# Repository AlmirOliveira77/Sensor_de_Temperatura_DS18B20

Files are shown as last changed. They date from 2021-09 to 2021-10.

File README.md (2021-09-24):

# Sensor de Temperatura DS18B20
## Integrantes: 
 - Almir de Oliveira Pereira <br>
 - Gabriel Faustino da Silva <br>
 - Jhônata Vinícius Da Silva Negreiros

## Descrição:

<p align="justify">Simular o controle de temperatura de um reservatório de água. Por meio do uso do microcontrolador ATmega328P, manteremos a temperatura entre 18º e 22º. Ao atingir a temperatura mínima ou máxima do intervalo, um sinal sonoro será emitido pelo buzzer, o que substituiria por um sistema de liga e desliga de uma resistência para manutenção da temperatura de um aquário, por exemplo. Com a utilização de um push button, poderemos criar um "modo silencioso", no qual ao invés do buzzer ser acionado nas circunstâncias específicas, um led vermelho seria acionado. As temperaturas são exibidas em tempo real no display LCD.

A escolha dos componentes do projeto se deu pela necessidade de utilização do Sensor de Temperatura DS18B20, o que nos guiou para a utilização dos mesmos, a fim de atingir com sucesso o uso do sensor na prática desenvolvida para esta disciplina de Técnicas de Prototipagem.

No decorrer do projeto, tivemos a oportunidade conhecer mais na prática os conceitos de prototipagem e sistemas embarcados aplicados por nosso professor. E durante a execução, pudemos perceber algumas dificuldades no que diz respeito ao encontro entre os integrantes do grupo para realização do projeto em si, o que se deve ao fato de estarmos vivenciando momentos nos quais a distância também se dá pela internet e vidas pessoais. Também tivemos algumas dificuldades no desenvolvimento da placa PCB, pois utilizamos um programa recentemente conhecido pelos integrantes do grupo, mas que foi superado com o esforço contínuo e em conjunto de todos.</p>

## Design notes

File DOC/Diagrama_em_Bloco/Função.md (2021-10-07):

<ul>
<li>A Bateria fornece energia para o microcontrolador, que a recebe por meio de um regulador de tensão;</li>
<li>O Microcontrolador distribui a energia entre os componentes, bem como trata os dados recebidos pelo sensor de temperatura, e aciona outros componentes de acordo com o tratamento dos dados previamente estabelecidos em código;</li>
<li>O Sensor de Temperatura realiza a medição da temperatura no ambiente em que ele estiver e envia os dados para o microcontrolador;</li>
<li>O Módulo I2C juntamente como Display LCD recebem as informações dos dados tratados pelo Microcontrolador e os exibe para o usuário;</li>
<li>O Buzzer é acionado quando a temperatura obtida pelo Sensor e tratada pelo Microcontrolador atinge um valor específico pré-programado;</li>
<li>O Push Button desativa o Buzzer, e aciona o “modo silencioso”, juntamente aos leds.</li>
</ul>

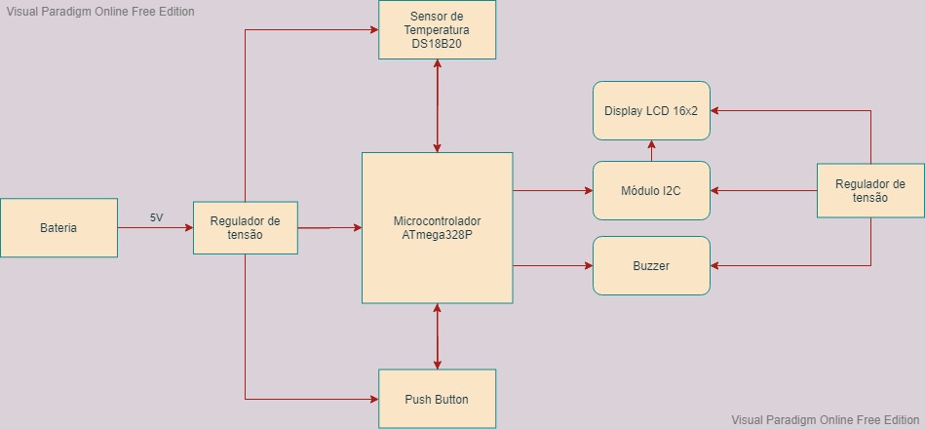
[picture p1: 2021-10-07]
DOC/Diagrama_em_Bloco/Diagrama_em_Bloco.jpeg

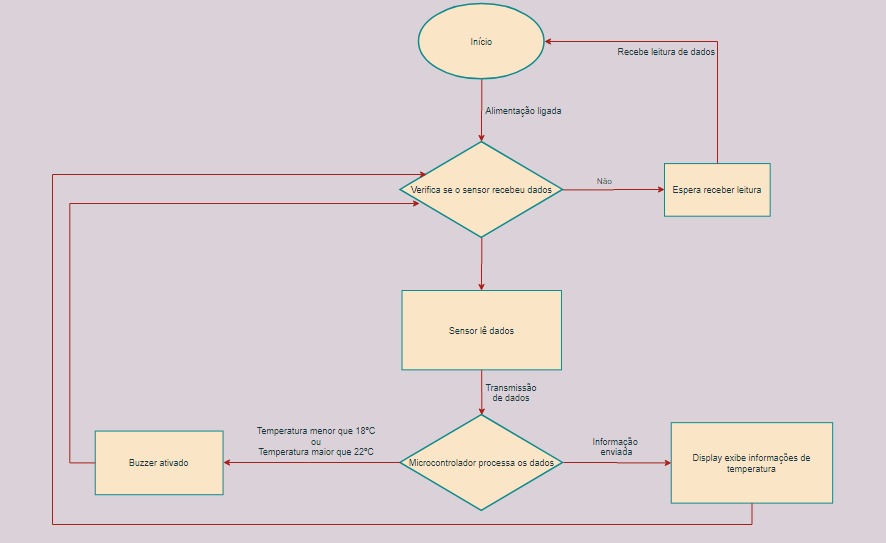
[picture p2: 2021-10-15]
FIRMWARE/Fluxograma.jpeg

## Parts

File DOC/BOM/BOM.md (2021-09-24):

<ul>
  <li>Buzzer</li>
  <li>Conector Jack</li>
  <li>Display LCD 16x2</li>
  <li>Jumpers</li>
  <li>Leds 5 mm</li>
  <li>Microcontrolador ATmega328P</li>
  <li>Módulo I2C para display LCD</li>
  <li>Push button</li>
  <li>Resistores</li>
  <li>Sensor de Temperatura DS18B20</li>
</ul>

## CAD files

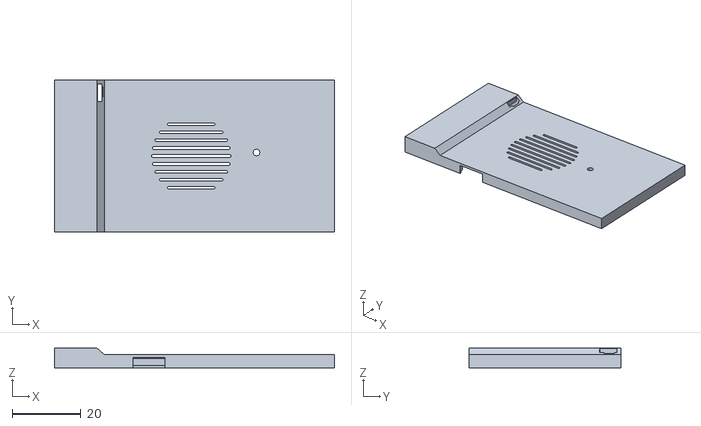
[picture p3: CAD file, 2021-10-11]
CASE/STL/Tampa.stl
81.3 x 44.1 x 5.77

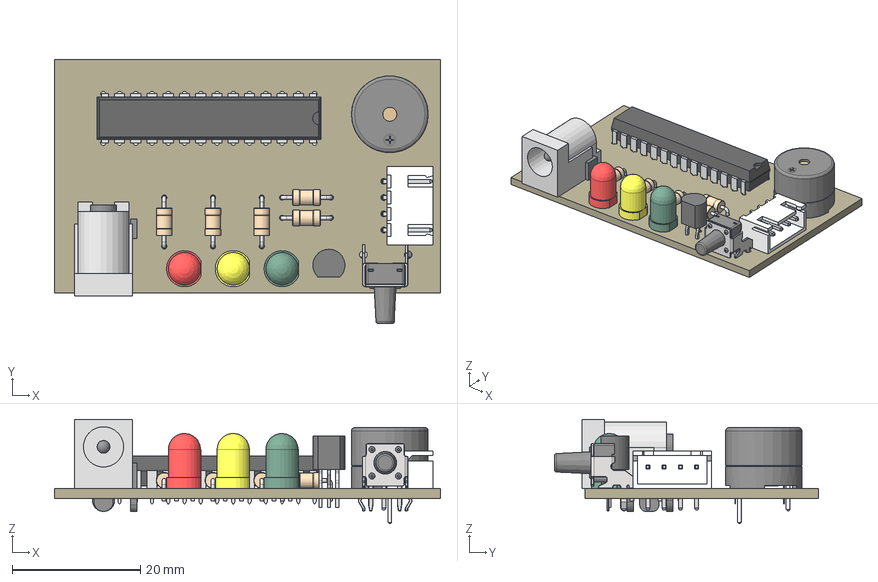
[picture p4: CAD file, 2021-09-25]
HARDWARE/Projeto_Temperatura.stp
60.3 x 41.3 x 16.3 mm
Board
TO-92
DIP28
TACTILE_SWITCH_PTH_RIGHT_ANGLE_KIT
LED5MM
LED5MM (1)
LED5MM (2)
F/CM12P
DCJ0202
0204/7
0204/7 (1)
0204/7 (2)
0204/7 (3)
0204/7 (4)
04PA

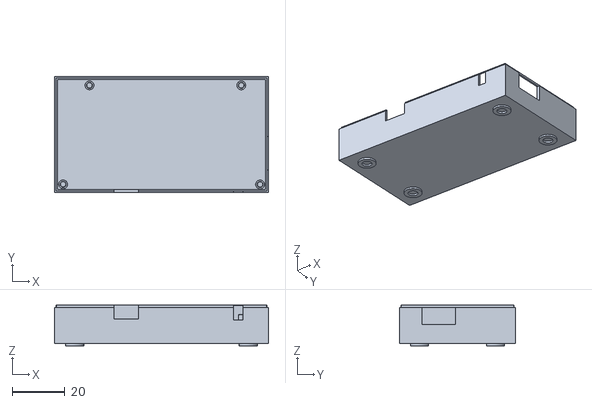
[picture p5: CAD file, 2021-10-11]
CASE/STL/Base.stl
81.3 x 44.1 x 15.4

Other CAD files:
CASE/F3D/Base.f3d
CASE/F3D/Case Completo.f3z
CASE/F3D/Tampa.f3d
HARDWARE/Projeto_Temperatura.f3d

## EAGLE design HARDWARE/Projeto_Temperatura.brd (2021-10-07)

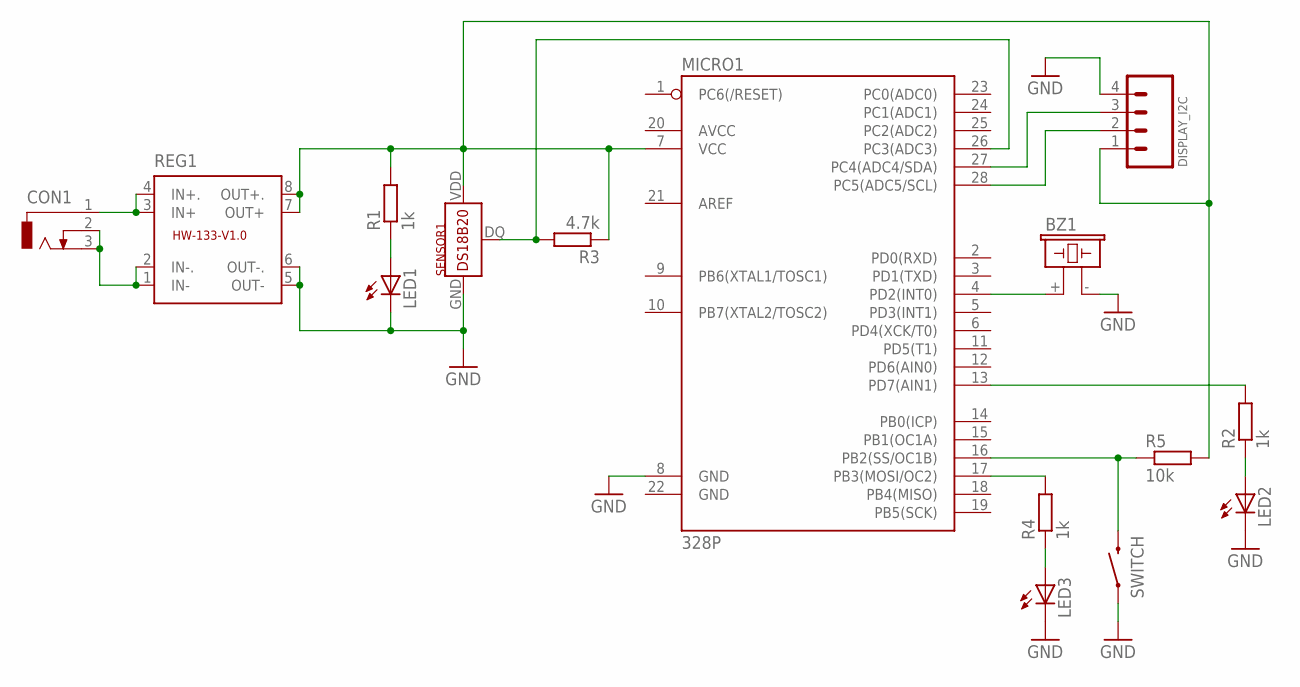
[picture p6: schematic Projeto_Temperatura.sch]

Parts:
BZ1: F/CM12P
CON1: DCJ0202
DISPLAY_I2C: MA04; 04PA
LED1, LED2, LED3: LED5MM
MICRO1: 328P; DIP28
R1, R2, R4: 1k; 0204/7
R3: 4.7k; 0204/7
R5: 10k; 0204/7
REG1: REGULADOR
SENSOR1: DS18B20; TO-92
SWITCH: MOMENTARY-SWITCH-SPST-PTH-RIGHT-ANGLE-KIT; TACTILE_SWITCH_PTH_RIGHT_ANGLE_KIT

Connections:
GND: BZ1.- (2), DISPLAY_I2C.4, LED1.K (C), LED2.K (C), LED3.K (C), MICRO1.8 (GND), REG1.5 (OUT-), REG1.6 (OUT-.), SENSOR1.GND (1), SWITCH.1
unnamed: LED2.A, R2.1
unnamed: MICRO1.13 (PD7(AIN1)), R2.2
unnamed: LED1.A, R1.1
unnamed: LED3.A, R4.1
unnamed: MICRO1.26 (PC3(ADC3)), R3.2, SENSOR1.DQ (2)
unnamed: MICRO1.17 (PB3(MOSI/OC2)), R4.2
unnamed: BZ1.+ (1), MICRO1.4 (PD2(INT0))
unnamed: MICRO1.16 (PB2(SS/OC1B)), R5.1, SWITCH.2
unnamed: DISPLAY_I2C.3, MICRO1.27 (PC4(ADC4/SDA))
unnamed: DISPLAY_I2C.2, MICRO1.28 (PC5(ADC5/SCL))
unnamed: DISPLAY_I2C.1, MICRO1.7 (VCC), R1.2, R3.1, R5.2, REG1.7 (OUT+), REG1.8 (OUT+.), SENSOR1.VDD (3)
unnamed: CON1.1, REG1.3 (IN+), REG1.4 (IN+.)
unnamed: CON1.2, CON1.3, REG1.1 (IN-), REG1.2 (IN-.)

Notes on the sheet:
REG1

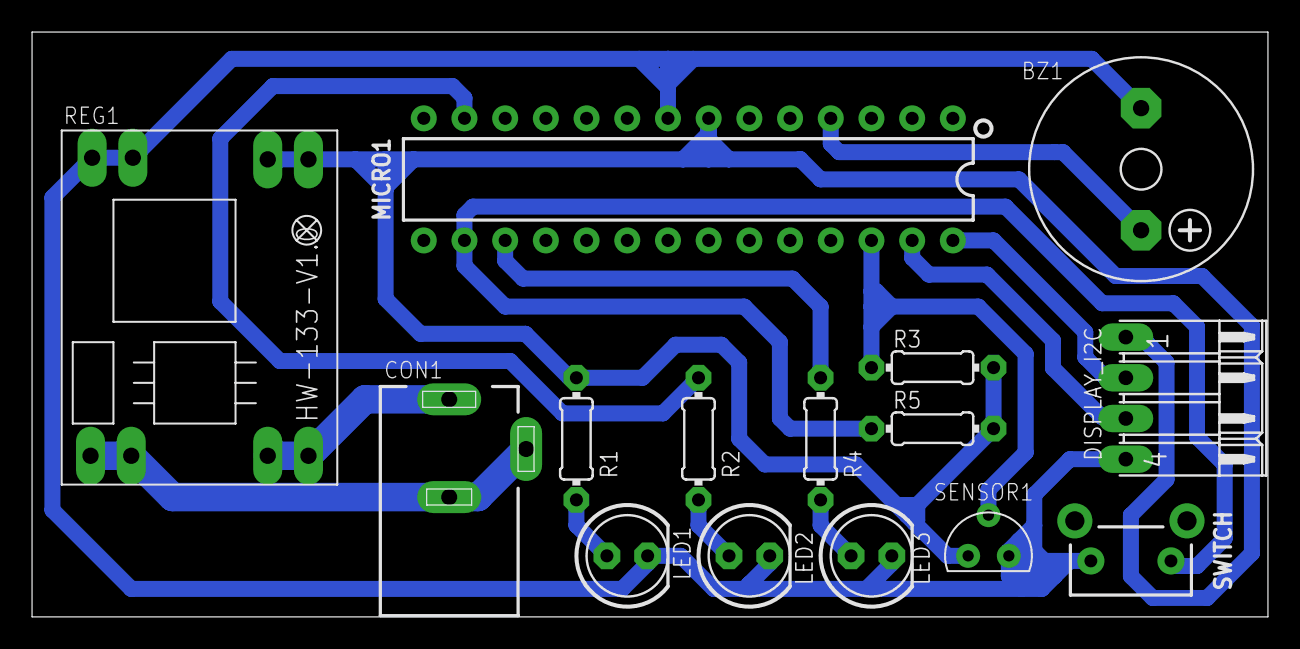
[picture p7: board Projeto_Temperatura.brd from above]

Board: 2 copper layers, 77.1 x 36.5 mm, 15 parts (0 on the bottom side), 14 nets.

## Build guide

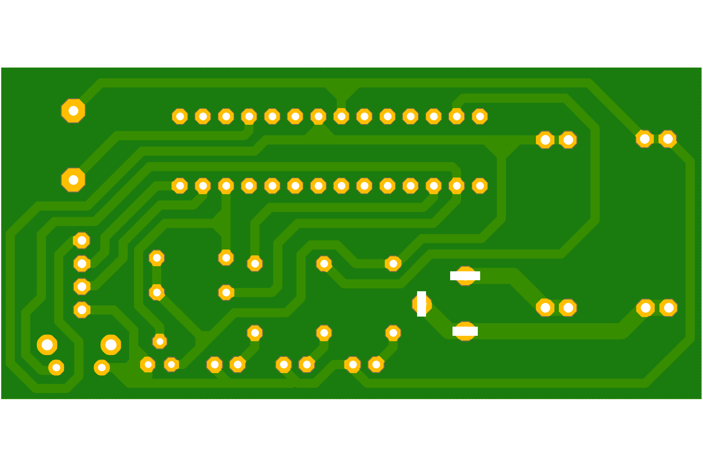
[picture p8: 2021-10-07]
HARDWARE/Prints/BOTTOM SIDE.png

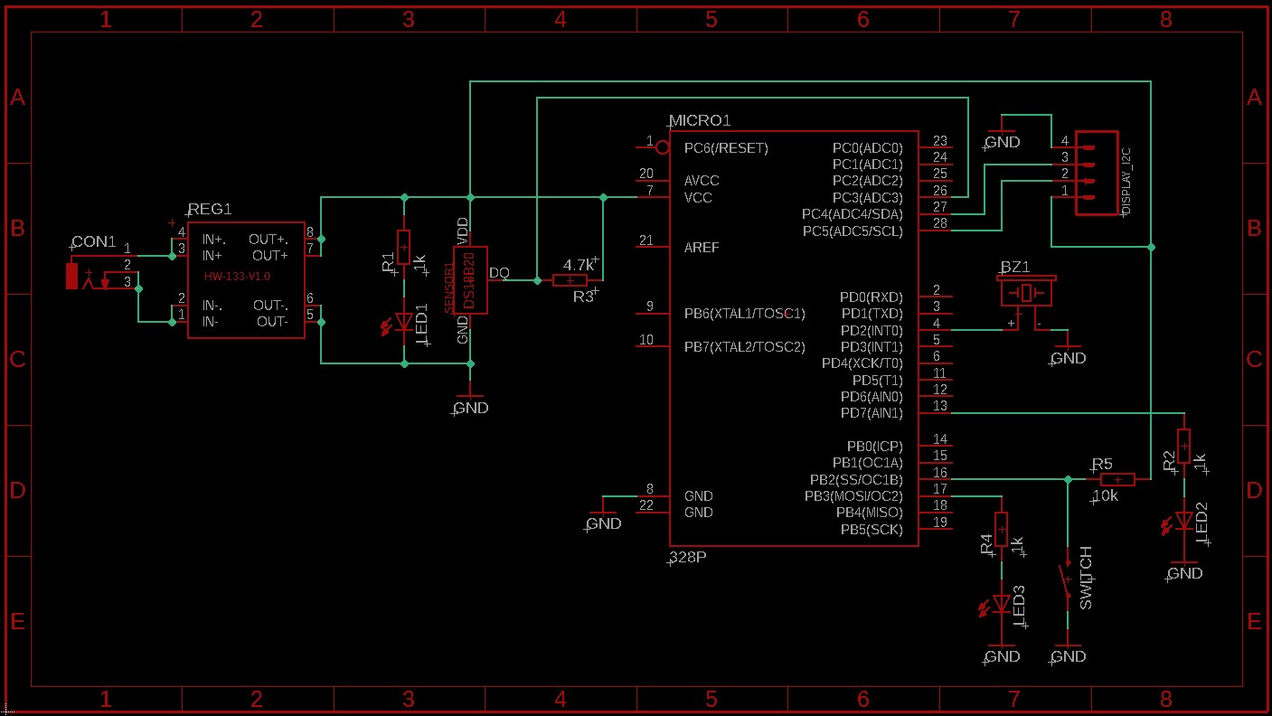
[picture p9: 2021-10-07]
HARDWARE/Prints/Esquema eletrico.jpg

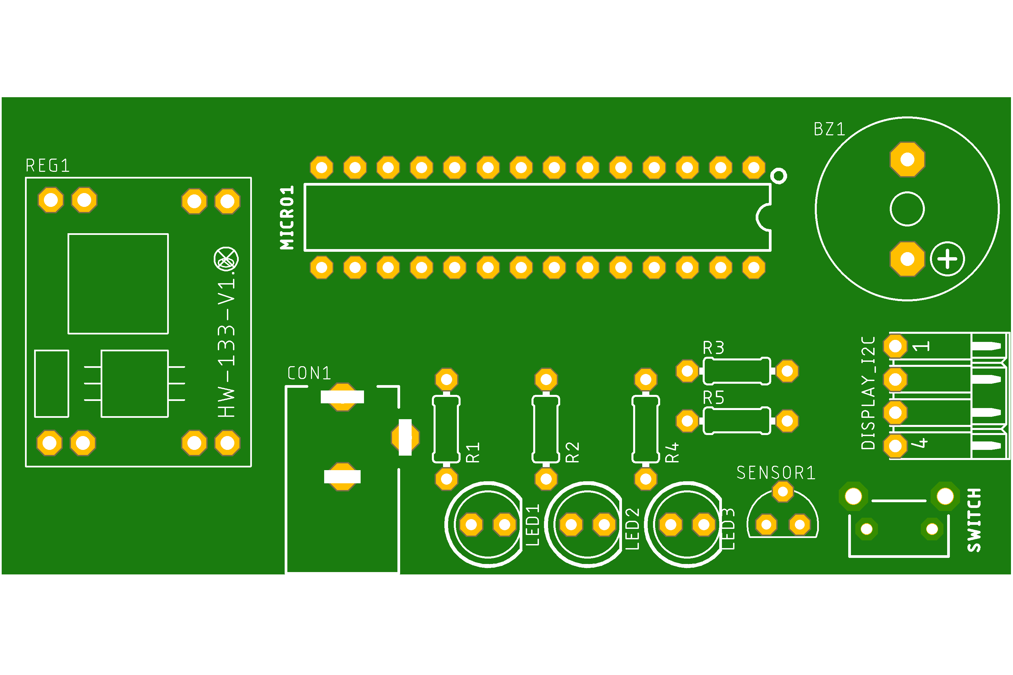
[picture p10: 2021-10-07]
HARDWARE/Prints/TOP SIDE.png

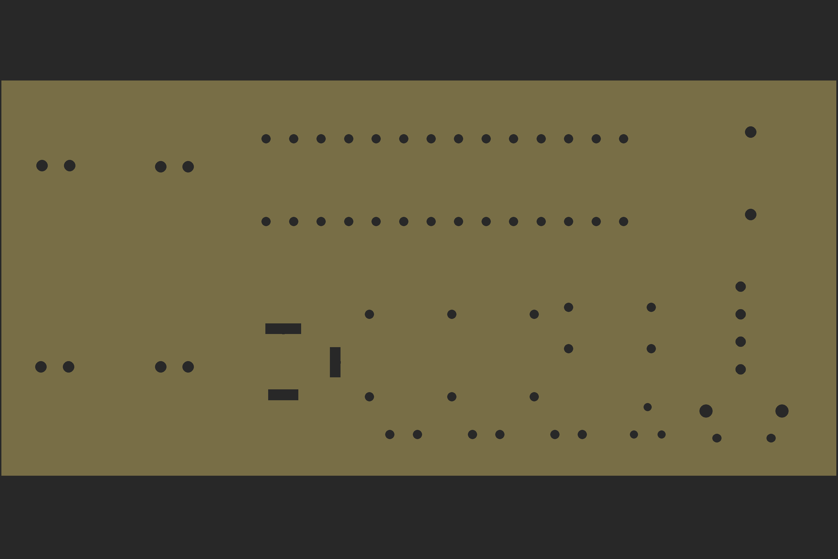
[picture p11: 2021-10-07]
HARDWARE/Prints/DRILLS.png

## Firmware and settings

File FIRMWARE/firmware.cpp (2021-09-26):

/*******************************************************************************
*     
*    IFPB - Campina Grande
*    Sensor de Temperatura DS18B20  
*    Disciplinas: Sistemas Embarcados 
*                 Técnicas de Prototipagem
*    Autores: Almir de Oliveira Pereira
*             Gabriel Faustino da Silva
*             Jhônata Vinícius da Silva Negreiros  
*    Data: 24/09/2021                    
*
*******************************************************************************/

#include <OneWire.h>
#include <DallasTemperature.h>
#include <LiquidCrystal_I2C.h>

//Conexões do terminal de sinal do DS18B20 e o botão com o microcontrolador atmega328p
const byte sensorPin = 9;
const byte botPin = 10;
const byte buzzerPin = 13;
const byte ledVermelho = 8;
const byte ledVerde = 7;

//Estado do botão
boolean estado = 0;

//Bibliotecas
OneWire pin(sensorPin); 
DallasTemperature bus(&pin);
DeviceAddress sensor;
 
//LCD
LiquidCrystal_I2C lcd(0x27,2,1,0,4,5,6,7,3, POSITIVE);

float temperatura_minima;
float temperatura_maxima;
float temperatura;

//Temperaturas de alarme
const float maxima = 22;
const float minima = 18;

void setup() {
  Serial.begin(9600); //inicia monitor serial
  lcd.begin(16, 2); //inicia lcd
  pinMode(botPin, INPUT_PULLUP); 
  pinMode(ledVermelho, OUTPUT);
  pinMode(ledVerde, OUTPUT);
  pinMode(buzzerPin, OUTPUT); 
  lcd.clear(); //limpa o disply
  bus.begin(); //inicializa o objeto bus
  bus.getAddress(sensor, 0); 
  temperatura_minima = 999;
  temperatura_maxima = -999;
}

void loop() {
  bus.requestTemperatures(); 
  temperatura = bus.getTempC(sensor); 
  
  if (temperatura < temperatura_minima){
   temperatura_minima = temperatura;
  }
  if (temperatura > temperatura_maxima){
   temperatura_maxima = temperatura;
  }
    
  mostra_temperatura(); 
  ativa_buzzer();   
  
  if (temperatura > maxima){ 
    Serial.println("TEMPERATURA ACIMA DO IDEAL");     
    sirene(); 
  } 
  else if  (temperatura < minima) {
    Serial.println("TEMPERATURA ABAIXO DO IDEAL"); 
    sirene();   
  } 
  else {
    Serial.println("TEMPERATURA ESTÁ IDEAL"); 
    digitalWrite(ledVermelho, LOW);
    noTone(buzzerPin); 
  }
}
 
void ativa_buzzer() { 
  if (!digitalRead(botPin)) {
       estado = !estado; 
       digitalWrite(ledVerde, estado);                     
       while(!digitalRead(botPin)) {}
       delay(150);
    }   
}

void mostra_temperatura() {
  lcd.setCursor(0,0);
  lcd.print("Temp.: "); 
  lcd.print(temperatura);
  lcd.write(B11011111); 
  lcd.print("C ");
  lcd.setCursor(0,1);
  lcd.print("L=");
  lcd.print (temperatura_minima);
  lcd.print("  H=");
  lcd.print (temperatura_maxima);
}

void sirene(){ 
  digitalWrite(ledVermelho, LOW);
  delay(50);
  ativa_buzzer();
  
  if (estado){ 
    noTone(buzzerPin);
    digitalWrite(ledVermelho, HIGH); 
    delay(150); 
    ativa_buzzer(); 
  } 
  else {
    for (int k=0; k<5; k++){
      ativa_buzzer(); 
      tone(buzzerPin, 1350); 
      delay(150);
      tone(buzzerPin, 1050); 
      delay(150); 
      digitalWrite(ledVermelho, HIGH);        
    }           
  }
} 

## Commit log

2021-09-24 Create BOM
2021-10-07 Rename reg to Regulador de Tensão

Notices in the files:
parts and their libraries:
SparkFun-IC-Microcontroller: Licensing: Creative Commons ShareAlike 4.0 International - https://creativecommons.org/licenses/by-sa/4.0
